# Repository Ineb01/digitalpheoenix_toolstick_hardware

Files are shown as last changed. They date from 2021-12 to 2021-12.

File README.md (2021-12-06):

# Digitalphoenix Toolstick
This repository includes the KiCad project files for the Digitalphenix Toolstick

## Clone
If you want to clone this repository it is important to clone it with all submodules e.g. 

`git clone --recurse-submodules https://github.com/Ineb01/digitalphoenix_toolstick_hardware.git`

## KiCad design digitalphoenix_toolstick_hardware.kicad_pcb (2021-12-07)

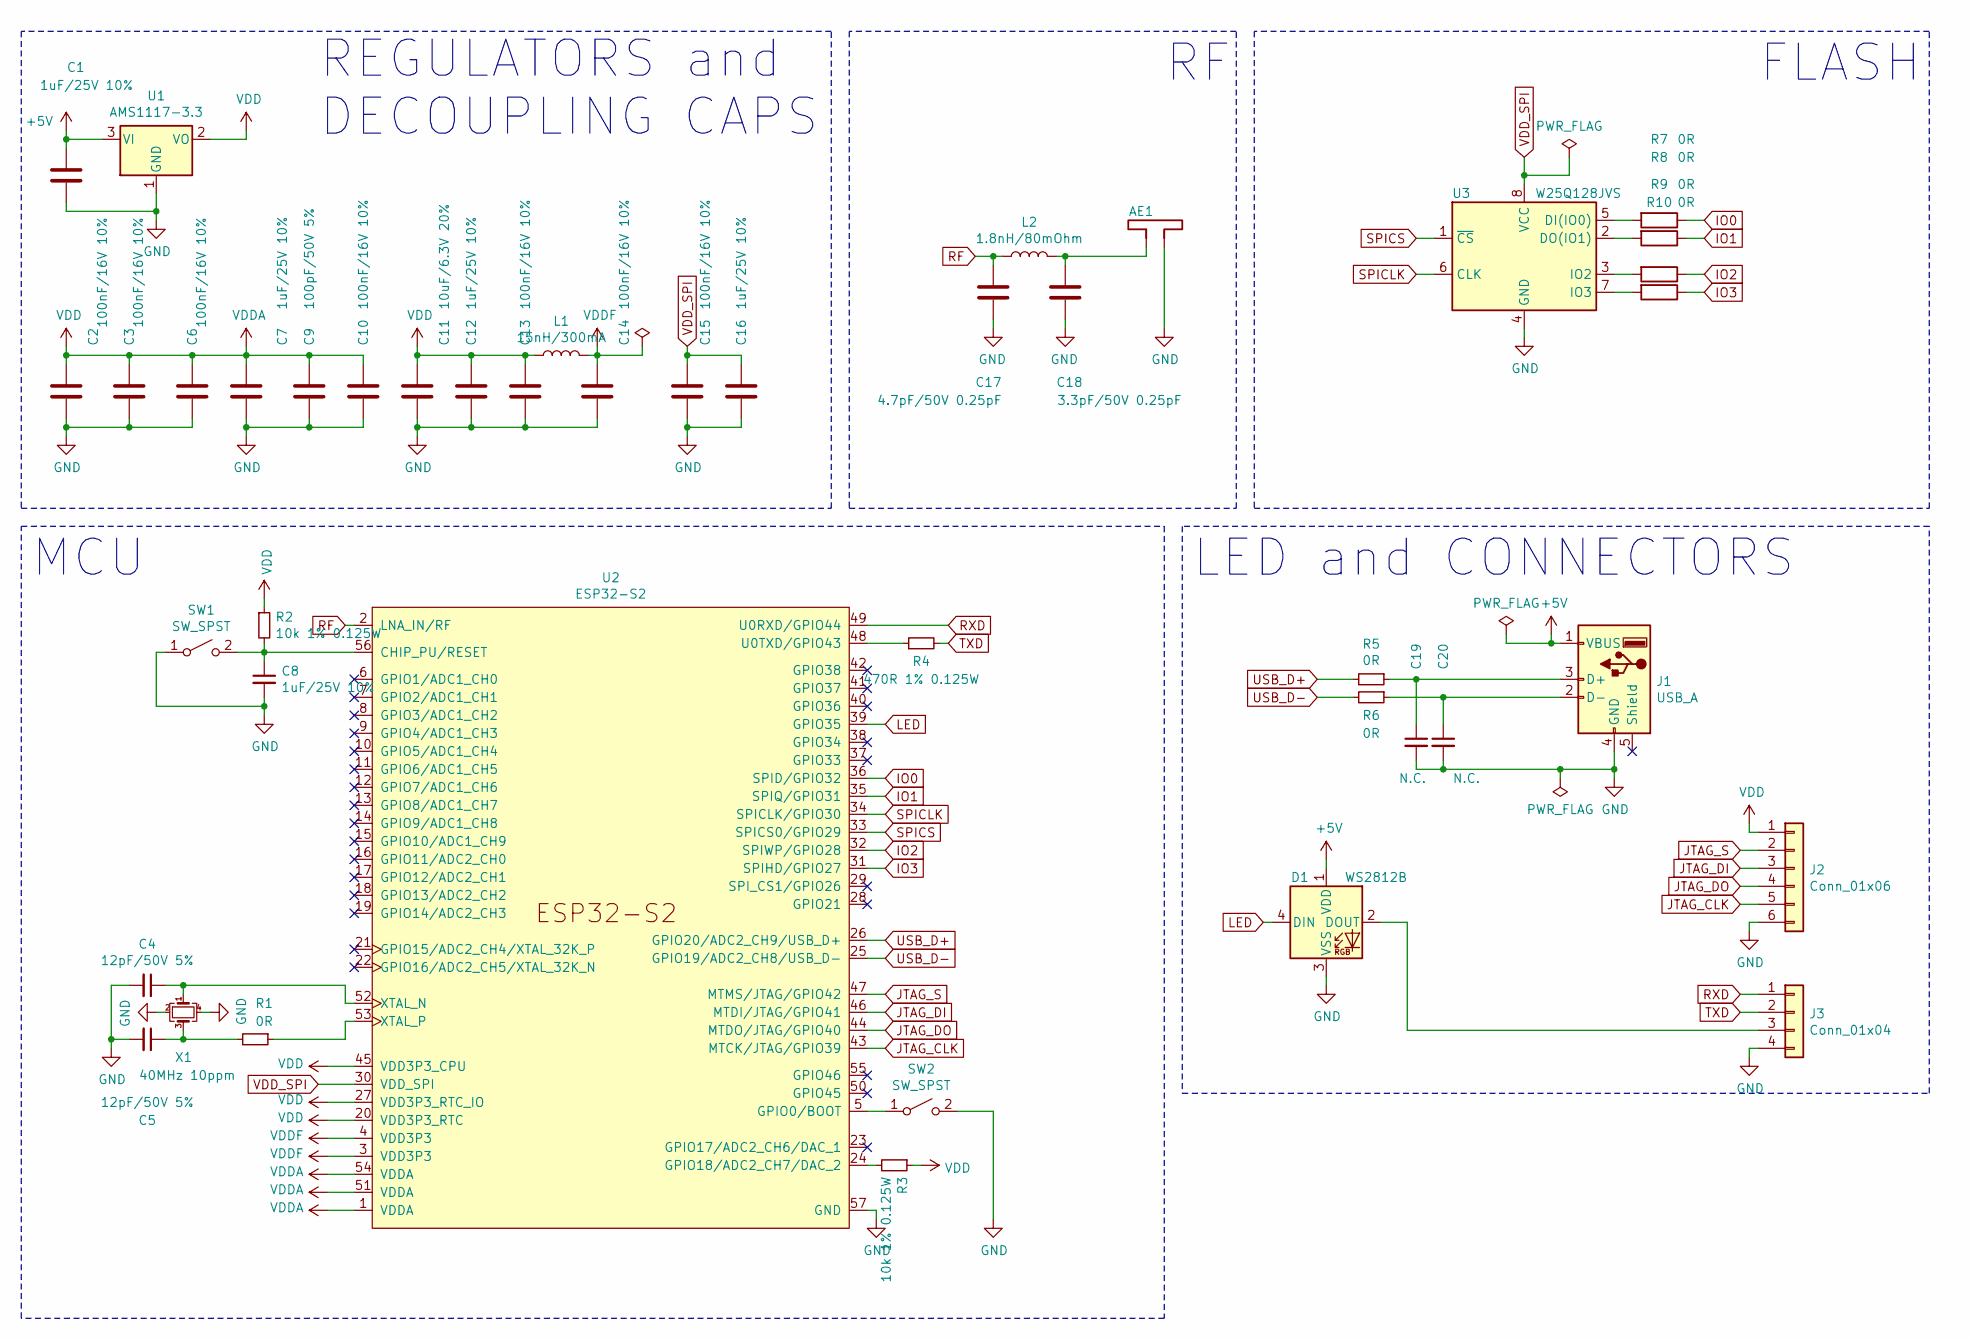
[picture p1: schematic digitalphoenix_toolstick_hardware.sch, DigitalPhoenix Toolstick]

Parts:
AE1: 2.4GHz 50R Antenna; Texas_SWRA117D_2.4GHz_Left
C1, C7, C8, C12, C16: 1uF/25V 10%; C_0402_1005Metric; LCSC_Number C52923
C2, C3, C6, C10, C13, C14, C15: 100nF/16V 10%; C_0402_1005Metric; LCSC_Number C1525
C4, C5: 12pF/50V 5%; C_0402_1005Metric; LCSC_Number C1547
C9: 100pF/50V 5%; C_0402_1005Metric; LCSC_Number C1547
C11: 10uF/6.3V 20%; C_0402_1005Metric; LCSC_Number C15525
C17: 4.7pF/50V 0.25pF; C_0402_1005Metric; LCSC_Number C1569
C18: 3.3pF/50V 0.25pF; C_0402_1005Metric; LCSC_Number C1565
C19, C20: N.C.; C_0402_1005Metric
D1: WS2812B; LED_WS2812B_PLCC4_5.0x5.0mm_P3.2mm; LCSC_Number C2890364
J1: USB_A; CONN-USB-A-PCB-TRACES
J2: Conn_01x06; PinSocket_1x06_P2.54mm_Vertical
J3: Conn_01x04; PinSocket_1x04_P2.54mm_Vertical
L1: 15nH/300mA; L_0402_1005Metric; LCSC_Number C27143
L2: 1.8nH/80mOhm; L_0402_1005Metric; LCSC_Number C77107
R1, R5, R6, R7, R8, R9, R10: 0R; R_0402_1005Metric; LCSC_Number C17168
R2, R3: 10k 1% 0.125W; R_0402_1005Metric; LCSC_Number C25744
R4: 470R 1% 0.125W; R_0402_1005Metric; LCSC_Number C25117
SW1, SW2: SW_SPST; SW_Push_SPST_NO_Alps_SKRK; LCSC_Number C455280
U1: AMS1117-3.3; SOT-223-3_TabPin2; LCSC_Number C6186
U2: ESP32-S2; QFN-56-1EP_7x7mm_P0.4mm_EP5.6x5.6mm; LCSC_Number C529594
U3: W25Q128JVS; SOIC-8_5.23x5.23mm_P1.27mm; LCSC_Number C97521
X1: 40MHz 10ppm; Crystal_SMD_3225-4Pin_3.2x2.5mm; LCSC_Number C90924

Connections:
+5V: C1.1, D1.1 (VDD), J1.1 (VBUS), U1.3 (VI)
GND: AE1.2, C1.2, C2.2, C3.2, C4.2, C5.2, C6.2, C7.2, C8.2, C9.2, C10.2, C11.2, C12.2, C13.2, C14.2, C15.2, C16.2, C17.2, C18.2, C19.2, C20.2, D1.3 (VSS), J1.4 (GND), J2.6, J3.4, SW1.1 (A), SW2.2 (B), U1.1 (GND), U2.57 (GND), U3.4 (GND), X1.2, X1.4
IO0: R7.1, U2.36 (SPID/GPIO32)
IO1: R8.1, U2.35 (SPIQ/GPIO31)
IO2: R9.1, U2.32 (SPIWP/GPIO28)
IO3: R10.1, U2.31 (SPIHD/GPIO27)
JTAG_CLK: J2.5, U2.43 (MTCK/JTAG/GPIO39)
JTAG_DI: J2.3, U2.46 (MTDI/JTAG/GPIO41)
JTAG_DO: J2.4, U2.44 (MTDO/JTAG/GPIO40)
JTAG_S: J2.2, U2.47 (MTMS/JTAG/GPIO42)
LED: D1.4 (DIN), U2.39 (GPIO35)
unnamed: AE1.1, C18.1, L2.2
unnamed: C4.1, U2.52 (XTAL_N), X1.1
unnamed: C5.1, R1.2, X1.3
unnamed: C8.1, R2.2, SW1.2 (B), U2.56 (CHIP_PU/RESET)
unnamed: C19.1, J1.3 (D+), R5.1
unnamed: C20.1, J1.2 (D-), R6.1
unnamed: D1.2 (DOUT), J3.3
unnamed: R1.1, U2.53 (XTAL_P)
unnamed: R3.2, U2.24 (GPIO18/ADC2_CH7/DAC_2)
unnamed: R4.1, U2.48 (U0TXD/GPIO43)
unnamed: R7.2, U3.5 (DI(IO0))
unnamed: R8.2, U3.2 (DO(IO1))
unnamed: R9.2, U3.3 (IO2)
unnamed: R10.2, U3.7 (IO3)
unnamed: SW2.1 (A), U2.5 (GPIO0/BOOT)
RF: C17.1, L2.1, U2.2 (LNA_IN/RF)
RXD: J3.1, U2.49 (U0RXD/GPIO44)
SPICLK: U2.34 (SPICLK/GPIO30), U3.6 (CLK)
SPICS: U2.33 (SPICS0/GPIO29), U3.1 (~CS)
TXD: J3.2, R4.2
USB_D+: R5.2, U2.26 (GPIO20/ADC2_CH9/USB_D+)
USB_D-: R6.2, U2.25 (GPIO19/ADC2_CH8/USB_D-)
VDD: C2.1, C3.1, C6.1, C7.1, C9.1, C10.1, C11.1, C12.1, C13.1, J2.1, L1.1, R2.1, R3.1, U1.2 (VO), U2.1 (VDDA), U2.20 (VDD3P3_RTC), U2.27 (VDD3P3_RTC_IO), U2.45 (VDD3P3_CPU), U2.51 (VDDA), U2.54 (VDDA)
VDDF: C14.1, L1.2, U2.3 (VDD3P3), U2.4 (VDD3P3)
VDD_SPI: C15.1, C16.1, U2.30 (VDD_SPI), U3.8 (VCC)

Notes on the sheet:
REGULATORS and DECOUPLING CAPS
FLASH
MCU
LED and CONNECTORS

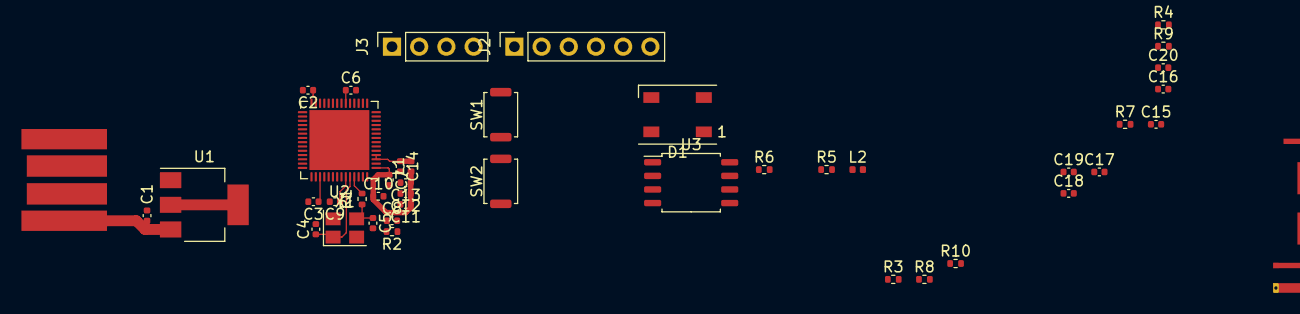
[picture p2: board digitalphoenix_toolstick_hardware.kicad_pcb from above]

Board: 2 copper layers, 43 parts (0 on the bottom side), 36 nets.

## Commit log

2021-12-06 Added Espressif KiCad libraries
2021-12-06 Basic schematic. unfinished for now
2021-12-06 Working on V0.1 Schematic
    [digitalphoenix_toolstick_hardware.sch]
2021-12-07 Footprints and starting the PCB
    [digitalphoenix_toolstick_hardware.kicad_pcb, digitalphoenix_toolstick_hardware.sch]
2021-12-07 More PCB work
    [digitalphoenix_toolstick_hardware.kicad_pcb, digitalphoenix_toolstick_hardware.sch]
